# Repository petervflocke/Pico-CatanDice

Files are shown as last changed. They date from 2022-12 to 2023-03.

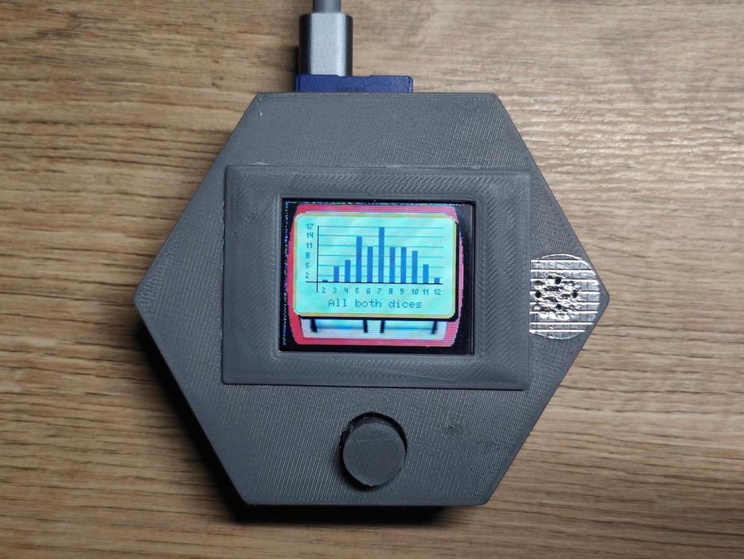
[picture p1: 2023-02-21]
docs/IMG20230221221516.jpg

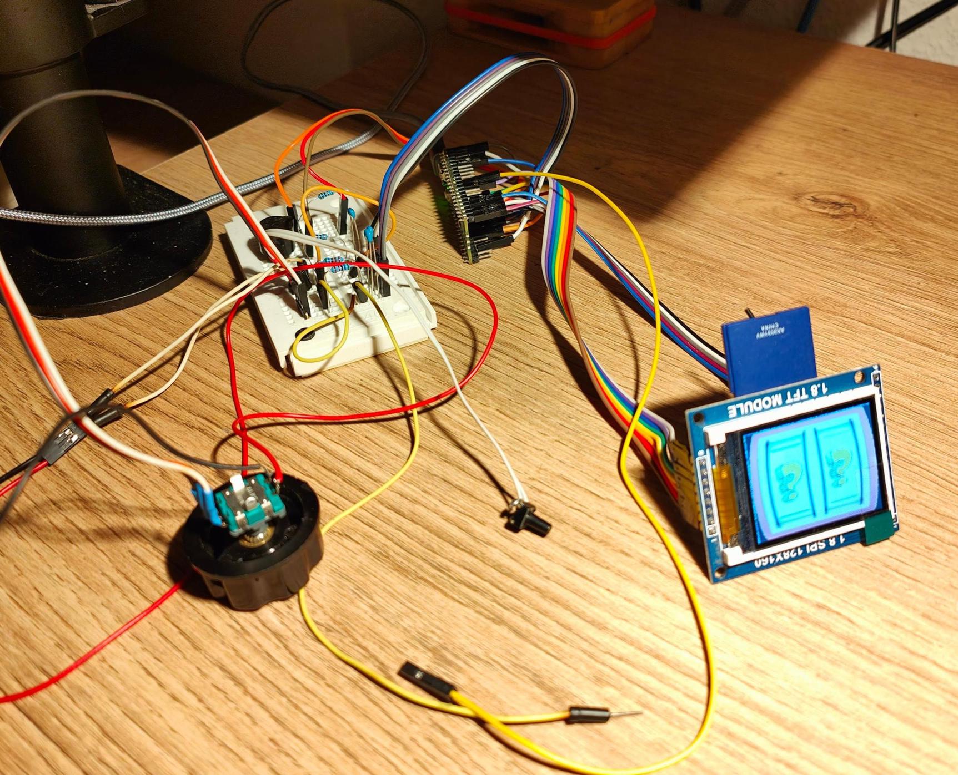
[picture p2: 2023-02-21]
docs/IMG20221118193249.jpg

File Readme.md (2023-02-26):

https://youtube.com/shorts/isAoaTnkfzQ

# An overengineered Catan Dice pretending to be speaking slot machine

Just to learn Raspberry Pi Pico, I've created this random generator I use now to play The Settlers of Catan.

## Main features

- Generating two random numbers from 1 to 6. The randomness is based on some none deterministic factors such as:

    - shifting an internal register
    - random time between button pressed
    - value of a two floating ADC inputs

- Animate generated numbers. Here pico pretends to be a slot machine with some simple sound efects

- Speak out result (showing is boring and pic has a lot of memory for some wav-data).
    - You can use at the same time simple [tone](https://www.arduino.cc/reference/en/language/functions/advanced-io/tone/) function and mix it with wav-data.

    - Wav-data is fully played using DMA, no IRQ no uProcesor cycles, so it does not stop main program. This just a PoC for any other sound efexct in the bacground.

- Show statistics from this game and all prevoius saved on a sd-card, to check if it is really [random](https://dilbert.com/strip/2001-10-25). 

## Miscelenius  

- Check 3D folder for enclousure (you may need a file to let usb and sd card in, in one version)
    - The top of the enclusure was designed for location of my elements, check pictures to copy it, otherwise your component may not match the 3D model.

- Check docs & wiring folder for schematics and some pictures from DIY

- BOM:

    - RPI Pico
    - LCD 1.8" with SD card slot
    - Phone mini loudspeaker 
    - Rotary Encoder
    - few resistors, capcitors

... Some further details in preperation or on a request.

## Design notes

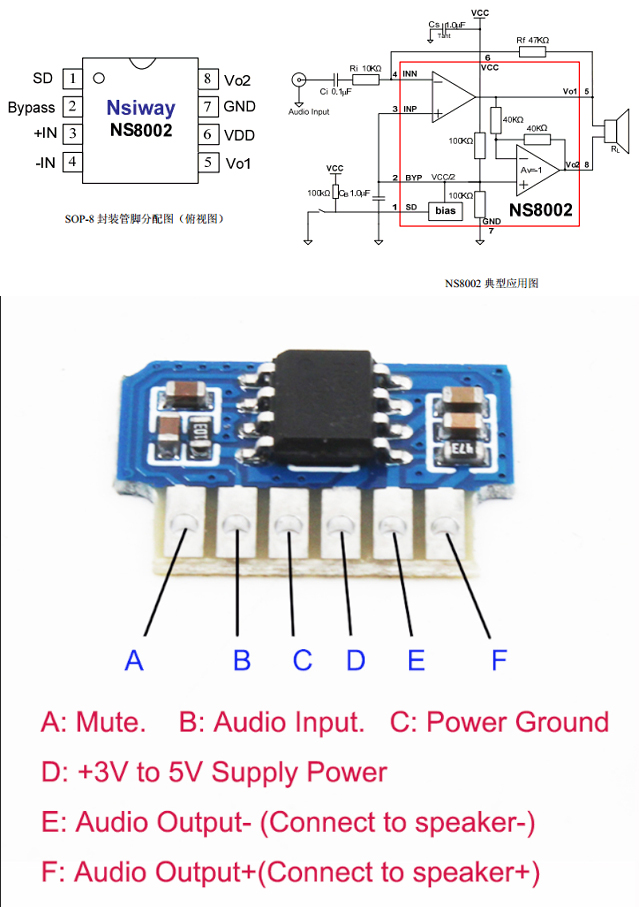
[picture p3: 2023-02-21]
docs/amplifier-NS8002.jpg

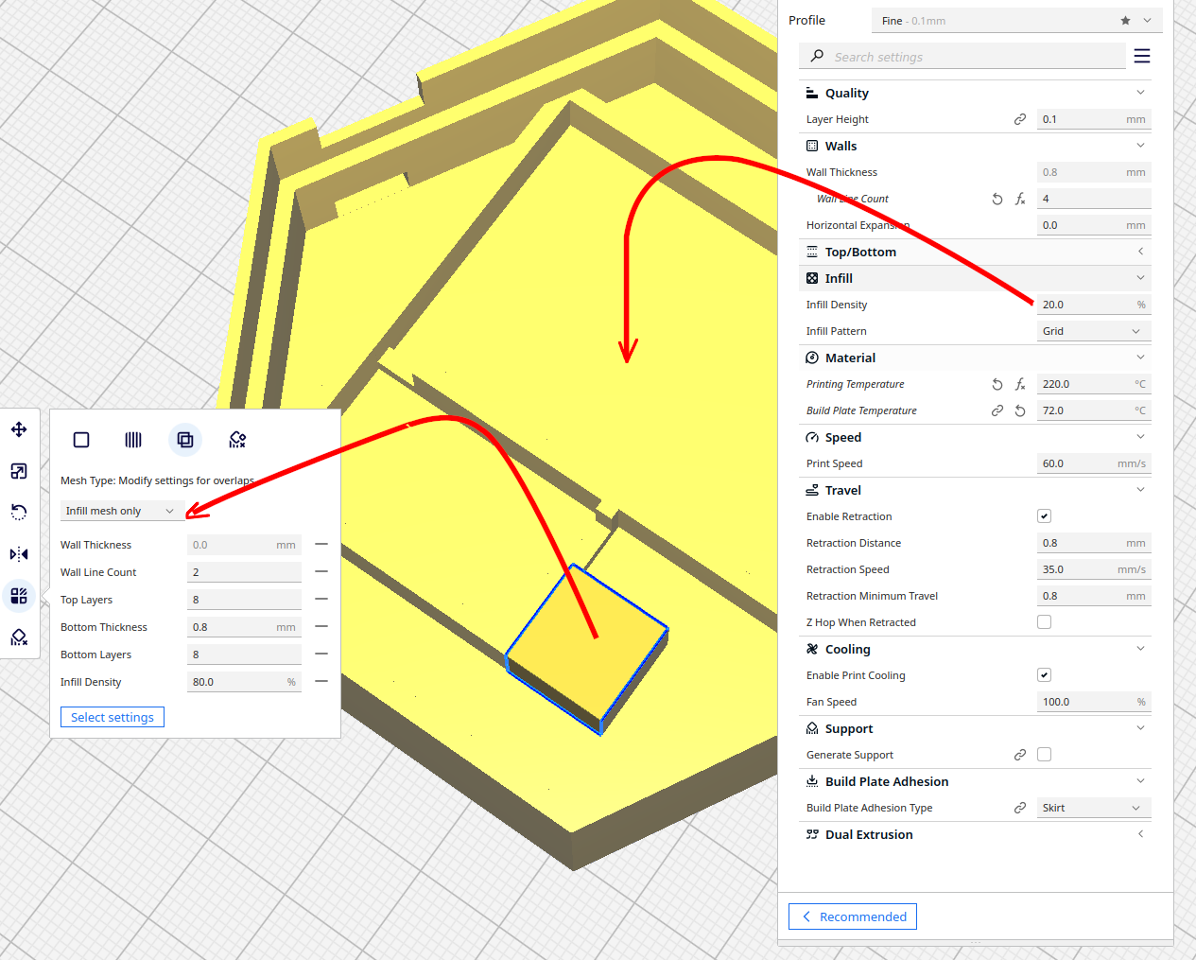
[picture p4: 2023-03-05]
3d/IncreaseDensityFill.png

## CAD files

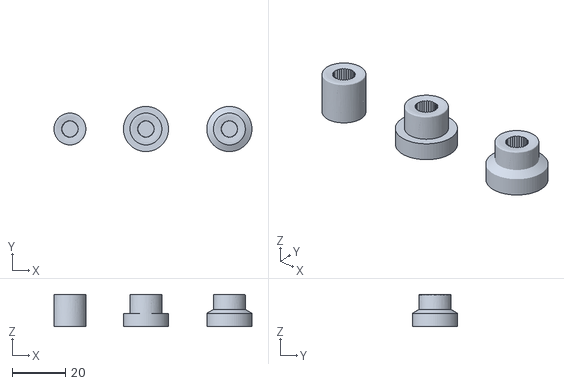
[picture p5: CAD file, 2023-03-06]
3d/Poti-v2.stl
74.5 x 17.0 x 12.1

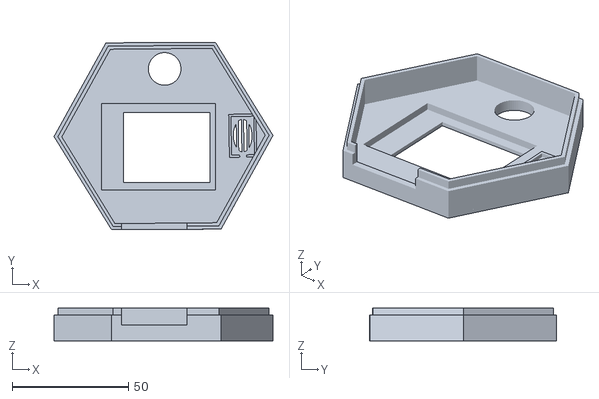
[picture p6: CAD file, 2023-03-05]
3d/CatanDiceBottomTop.stl
94.0 x 80.5 x 14.0

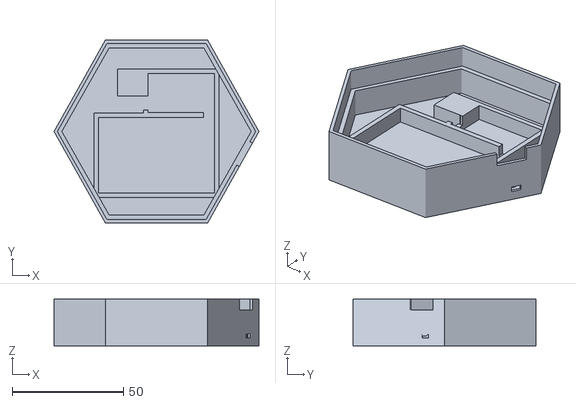
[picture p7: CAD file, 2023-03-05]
3d/CatanDiceBottom.stl
92.0 x 82.0 x 21.0

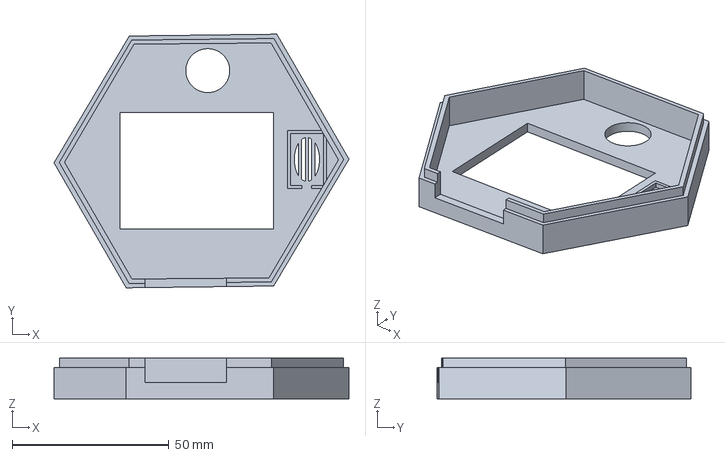
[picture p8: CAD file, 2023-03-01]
3d/CatanDice2.3mf
94.0 x 80.8 x 13.0 mm

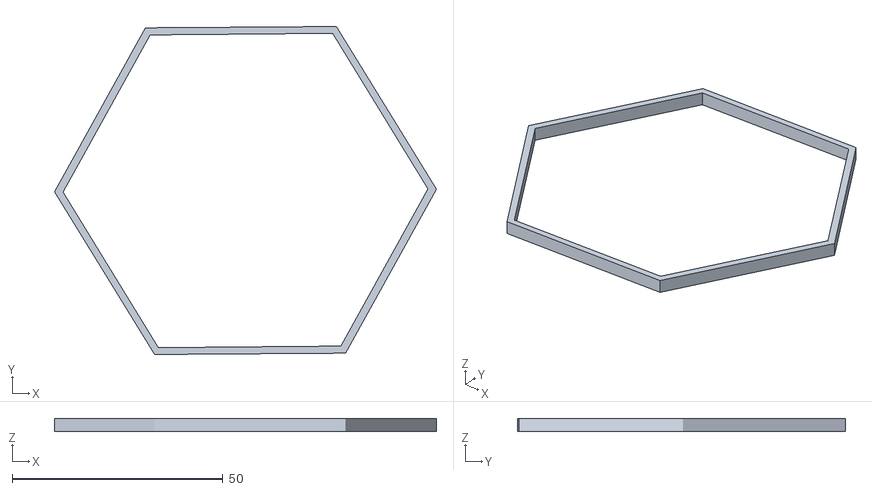
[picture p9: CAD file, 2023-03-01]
3d/CatanDice distance.stl
90.7 x 77.8 x 3.20

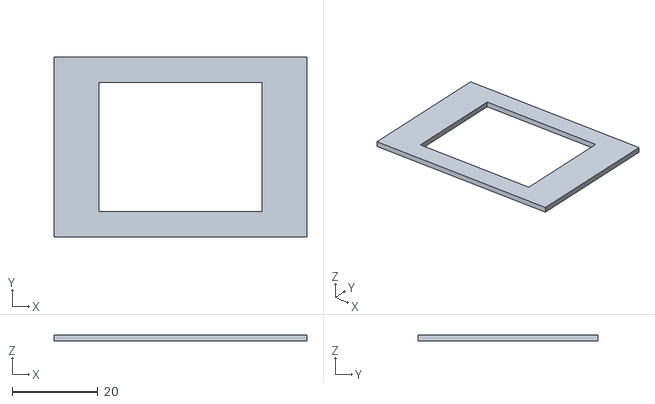
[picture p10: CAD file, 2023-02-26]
3d/CatanDiceBottomTopTop.stl
59.0 x 42.0 x 1.50

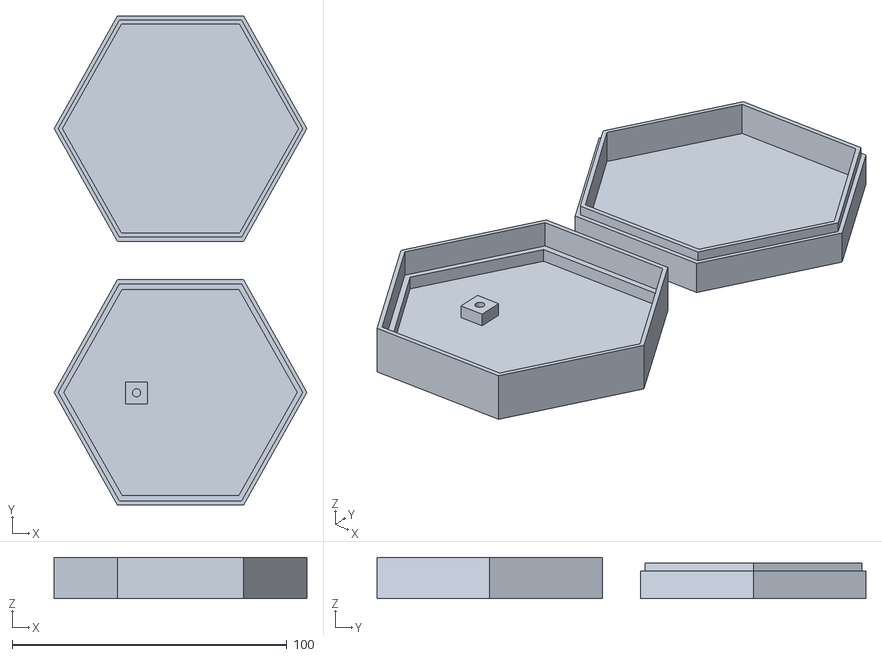
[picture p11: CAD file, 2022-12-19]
3d/CatanDice.stl
92.0 x 178.0 x 15.0

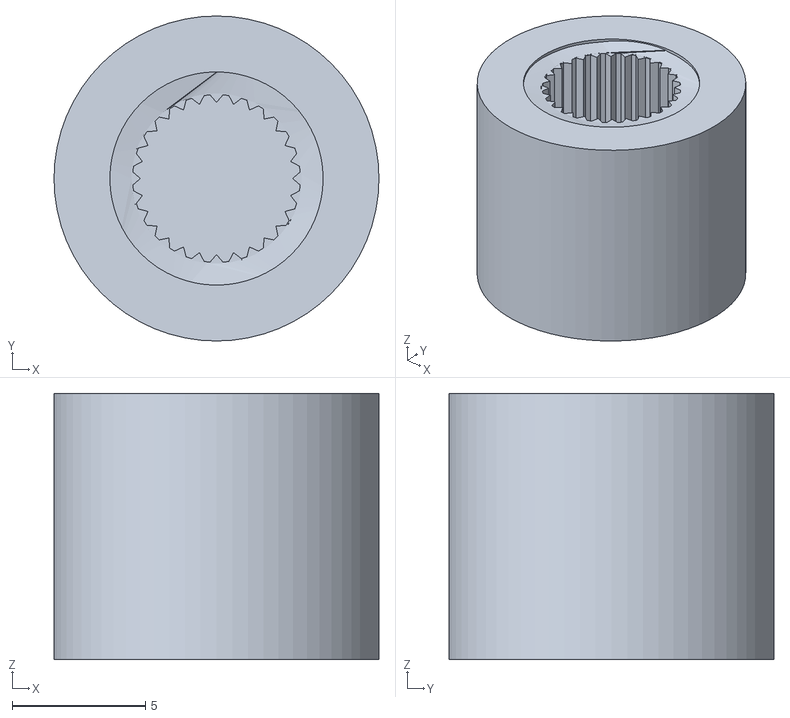
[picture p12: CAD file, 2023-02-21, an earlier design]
3d/Poti.stl
12.2 x 12.2 x 10.0

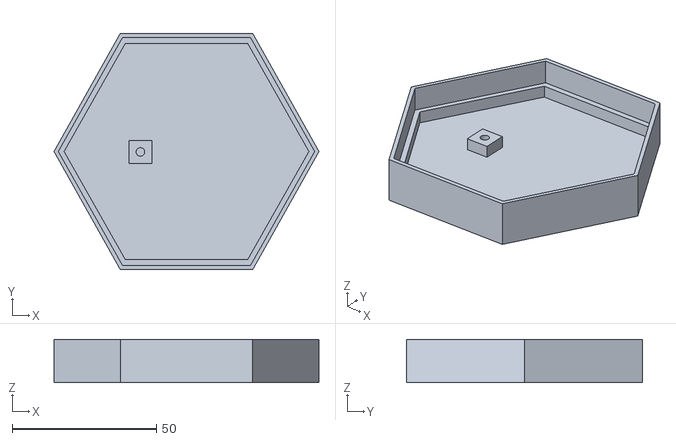
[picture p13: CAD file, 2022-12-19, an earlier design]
3d/CatanDice (1).stl
92.0 x 82.0 x 15.0

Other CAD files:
3d/CatanDice (3).stl
3d/CatanDice (2).stl

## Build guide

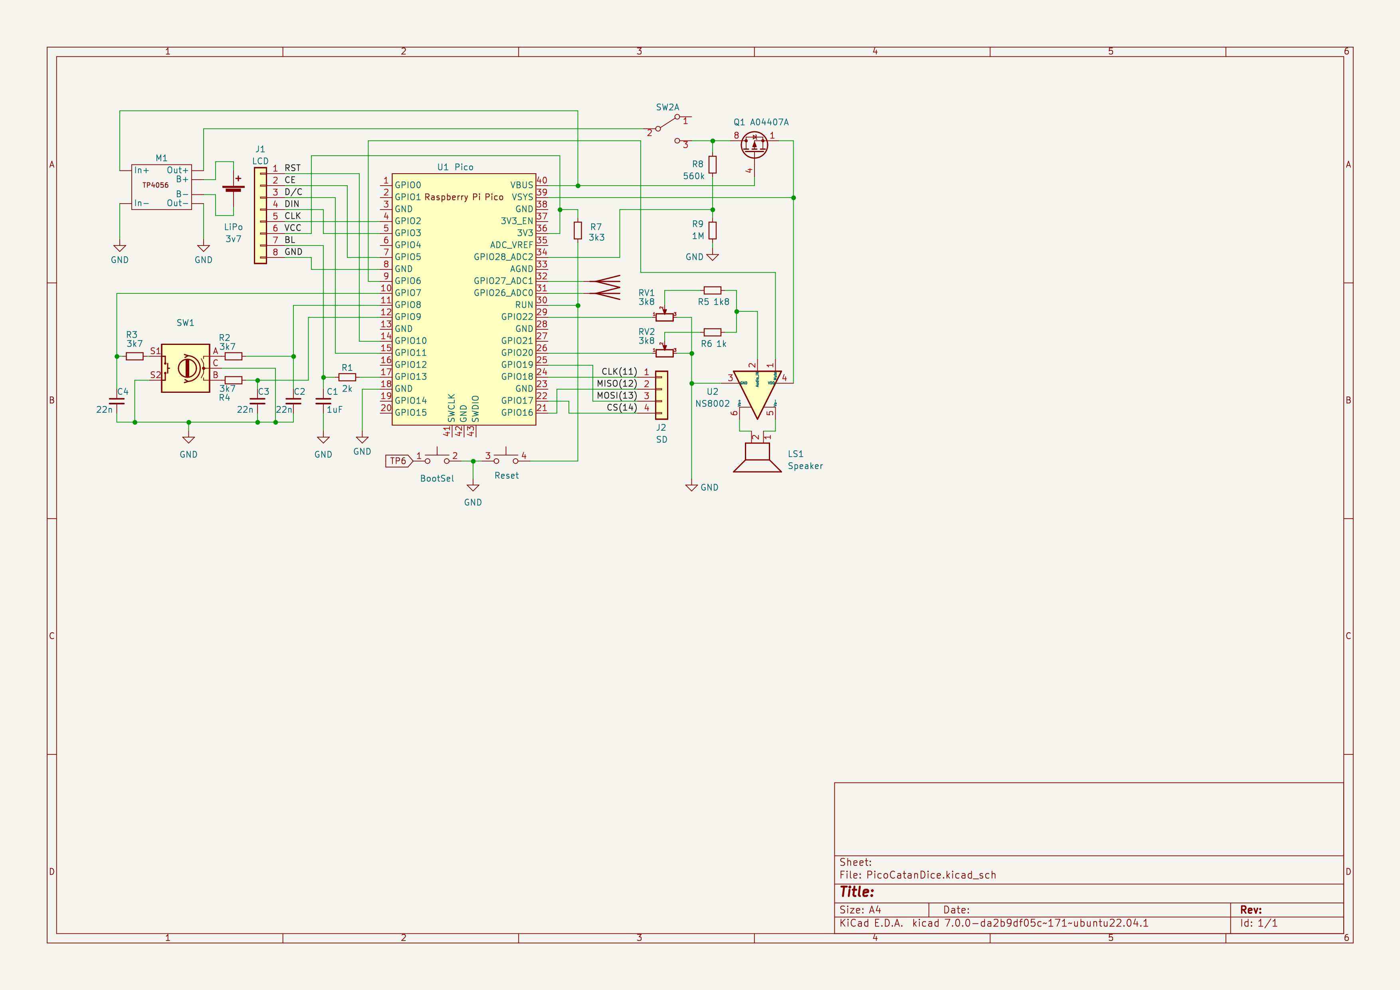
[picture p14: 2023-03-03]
wiring/PicoCatanDice.png

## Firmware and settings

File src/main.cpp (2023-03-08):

/* cSpell:disable */
// #define DEBUG_RANDOM
#ifndef ARDUINO_ARCH_RP2040
  #error works only on earlephilhower core
#endif
#include "Arduino.h"
#include <stdio.h>
#include "hardware/gpio.h"
#include "hardware/regs/rosc.h"
#include "hardware/regs/addressmap.h"
#include <TFT_eSPI.h> 
#include "Free_Fonts.h"
#include <RingBufCPP.h>
#include <ptScheduler.h>
#include "SdFat.h"
#include "settings.h"
#include "songs.h"
#include "logger.h"
#include "graphics.h"
#include "keyhandler.h"
#include "statehandler.h"
#include "randomgenerator.h"
#include "runningaverage.h"

#include "WavPwmAudio.h"
#include "WAVData.h"

 const unsigned short *wavs[]={
  wav2,
  wav3,
  wav4,
  wav5,
  wav6,
  wav7,
  wav8,
  wav9,
  wav10,
  wav11,
  wav12
 };
#define MAX_COUNT 10


TFT_eSPI tft = TFT_eSPI();  
TFT_eSprite scrollText1  = TFT_eSprite(&tft);

ptScheduler  pt_random_waiting_for_press = ptScheduler(PT_TIME_2S);
ptScheduler  pt_random_display = ptScheduler(PT_TIME_20MS);
ptScheduler  pt_random_say = ptScheduler(PT_TIME_4S);
ptScheduler  pt_delay_bird = ptScheduler(ScreenSaverAnimationDelay);
ptScheduler  pt_song = ptScheduler(1);

// volatile long secuenceN = 0;

// ring buffer
RingBufCPP<struct Event, MAX_NUM_ELEMENTS> buf;

SdFat32 sd;

boolean sdCardOK;
int noteIndex;
state_type stateTable[stateNumber][eventNumber];

RunningAverage ra;

void setup()
{
  Serial.begin(115200);
  // while (!Serial) {
  //   yield();
  // }
  
  // Prepare pins and buttons handling
  pinMode(LED_PIN, OUTPUT);
  pinMode(MutePin, OUTPUT);
  pinMode(pinBut, INPUT_PULLUP);
  pinMode(pinA, INPUT_PULLUP);
  pinMode(pinB, INPUT_PULLUP);

  analogReadResolution(12);
  for (int i = 0; i < maxSample; i++) {
    ra.addValue(analogRead(BatPin));
    delay(10);
  }

  WavPwmInit(GPIO_AUDIO_OUT_LEFT);
  digitalWrite(MutePin, 0); // unmute amplifier

  tft.init();   // old tft.begin();
  tft.setRotation(3);  // landscape upside down
  tft.setSwapBytes(true);

  tft.pushImage(0, 0, catanWidth, catanHeight, catan);
  // sdCardOK = SD.begin(PIN_SD_CS, SPI);
  // sdCardOK = sd.cardBegin(SD_CONFIG);
  sdCardOK = sd.begin(SD_CONFIG);
  if (sdCardOK) {
    // delay(1000);
    // Serial.println("Start reading from SD");
    // long lFreeKB = sd.vol()->freeClusterCount();
    // lFreeKB *= sd.vol()->sectorsPerCluster()/2;
    // Serial.println(lFreeKB);
    sdCardOK = myLogger(sd);
  }
  
  myStat.currentDur = millis();
  if (sdCardOK) {
  // Serial.println("Start writing to SD");
    sdCardOK = saveResult(1, 0, 0, 0, 0, 0, 0, myStat.currentDur);
  }

  if (sdCardOK) {
    tft.setTextColor(TFT_WHITE);
    tft.drawString("SD card OK", SDX2e, SDYe, 2);
    delay(2000);
  } else {
    showSDError(tft);
    tft.setTextColor(TFT_RED);
    while (gpio_get(pinBut)) {
      tft.fillRect(SDX1e, SDYe, 45, 16, sdcardback);
      delay(100);
      tft.drawString("ERROR", SDX1e, SDYe, 2);
      delay(100);
    }    
  }
  tft.fillScreen(TFT_BLACK);
  tft.pushImage(0, 0, counterWidth, counterHeight, counter);
  for (unsigned long i=0; i<=(gHeight-1)*gWidth*1; i+=gWidth*4) {
    genTone();
    tft.pushImage(lx, ly, gWidth, gHeight, space+i);
    tft.pushImage(rx, ry, gWidth, gHeight, space+i);
    delay(20);
  }
  // attached pin irq
  gpio_set_irq_enabled_with_callback(pinBut, GPIO_IRQ_EDGE_FALL | GPIO_IRQ_EDGE_RISE , true, &gpio_callback);
  gpio_set_irq_enabled(pinA, GPIO_IRQ_EDGE_FALL | GPIO_IRQ_EDGE_RISE , true);
  gpio_set_irq_enabled(pinB, GPIO_IRQ_EDGE_FALL | GPIO_IRQ_EDGE_RISE , true);

  initState();

  // unsigned long tt = millis();
  if (sdCardOK) {
    // Serial.println("Start reading");
    if (sdCardOK=!readResult()) {
      // Serial.println("Reading ok");  
    };
  } else myStat.inputError = false;


  // uint32_t freeKB = SD.vol()->freeClusterCount();
  // freeKB *= SD.vol()->blocksPerCluster()/2;
  // Serial.print("Free space KB: ");
  // Serial.println(freeKB);


/*   
  Serial.print("Stop reading after: ");
  Serial.println(millis()-tt);
  // delay(1500-tt);


  Serial.print("allDur     : "); Serial.println(myStat.allDur);
  Serial.print("currentDur : "); Serial.println(myStat.currentDur);
  Serial.print("numberGames: "); Serial.println(myStat.numberGames);
  Serial.print("numberDraws: "); Serial.println(myStat.numberDraws);
  Serial.print("inputError : "); Serial.println(myStat.inputError);
  Serial.print("lineNumberError : "); Serial.println(myStat.lineNumberError);

  for (int i=0; i<6; i++) {
    Serial.print(" L "); Serial.print(i+1); Serial.print(" : "); Serial.print(statTabLg[i]); Serial.print(" - "); Serial.println( double(statTabLg[i])/float(myStat.numberDraws)*100.0, 2 );
  }
  for (int i=0; i<6; i++) {
    Serial.print(" R "); Serial.print(i+1); Serial.print(" : "); Serial.print(statTabRg[i]); Serial.print(" - "); Serial.println( double(statTabRg[i])/float(myStat.numberDraws)*100.0, 2 );
  }
  Serial.print("i : "); Serial.println(myStat.numberDraws);
  for (int i=0; i<11; i++) {
    Serial.print(" S "); Serial.print(i+2); Serial.print(" : "); Serial.print(statTabSg[i]); Serial.print(" - "); Serial.println( double(statTabSg[i])/float(myStat.numberDraws)*100.0, 2 );
  }
*/
}


void loop()
{ 
  u_int32_t statCnt=0;

  statTab_t  statTabL = {0, 0, 0, 0, 0, 0};
  statTab_t  statTabR = {0, 0, 0, 0, 0, 0};
  statTabS_t statTabS = {0, 0, 0, 0, 0, 0, 0, 0, 0, 0, 0};

  int scrollDelay;
  int steps;

  int rnd1=0; 
  int rnd2=0;
  uint32_t seedL;
  uint32_t seedR;
  int rndSum;
  int messageGLen;
  int messageIndex;
  unsigned long screenSaver = 0;
  
  unsigned int birdN;
  unsigned int BirdX;
  unsigned int BirdY;

  unsigned long loop_i;
  int loop_j;
  bool loop_z;
  bool loop_w;

  char MessageStr[MessageLen];

  uint16_t resultFrameColor;

  unsigned long duration1;
  unsigned long duration2;

  duration1 = millis();

  state_type current_state = random_waiting_for_press;
  state_type former_state = none;
  bool doBreak;

  #define MAXBACKLIGHT 16
  int backlight = MAXBACKLIGHT;

  while (true) {
    if (!buf.isEmpty())
      {
        // current_state = key_logic(former_state);
        current_state = key_logic(current_state);
      }  
/*     if (current_state != former_state) {
      // Serial.print("Old / New State: "); 
      // Serial.print(former_state);
      // Serial.print("->");
      // Serial.println(current_state);
      former_state = current_state;
    }
*/
    if (current_state != former_state) {
      ra.addValue(analogRead(BatPin));
    }

    if (current_state == screen_saver) {
      if (current_state != former_state) {
        tft.pushImage(0, 0, catanWidth, catanHeight, catan);
        birdN = birdMaxN;
        former_state = current_state;
        BirdX = 15; // initilaized only for first removal, then random
        BirdY =  1;
      }
      if (pt_delay_bird.call()) {
        if (birdN >= birdMaxN) {
          restoreBack(tft, BirdX + tabBirds[birdMaxN-1].bx, BirdY + tabBirds[birdMaxN-1].by, tabBirds[birdMaxN-1].b_width, tabBirds[birdMaxN-1].b_height, catanWidth, catan);          
          birdN = 0;
          BirdX = random(15, 46);
          BirdY = random(1, 16);
        }
        else {
          if (birdN > 0) restoreBack(tft, BirdX + tabBirds[birdN-1].bx, BirdY + tabBirds[birdN-1].by, tabBirds[birdN-1].b_width, tabBirds[birdN-1].b_height, catanWidth, catan);
          tft.pushImage(BirdX + tabBirds[birdN].bx, BirdY + tabBirds[birdN].by, tabBirds[birdN].b_width, tabBirds[birdN].b_height, tabBirds[birdN].bird, TFT_WHITE);
          drawTime(tft, 65, 100, duration1);
          birdN += 1;
        }
      }
    } 
    if ( (current_state == ibacklight) || (current_state == dbacklight) ) {
      if (current_state != former_state) {
        int bl = (current_state == ibacklight)? +1:-1;
        backlight += bl;
        if ( backlight < 1  ) backlight = 1;
        if ( backlight > MAXBACKLIGHT ) backlight = MAXBACKLIGHT;
        Serial.println(map(backlight, 1, MAXBACKLIGHT, 1, 128));
        if (backlight == MAXBACKLIGHT) 
          analogWrite(TFT_BL, 255);
        else
          analogWrite(TFT_BL, map(backlight, 1, MAXBACKLIGHT, 1, 128));
        former_state = current_state;
      }
      key_clean();
      key_none();      
    }    
    if (current_state == random_waiting_for_press) {
      if (current_state != former_state) {
        tft.pushImage(0, 0, counterWidth, counterHeight, counter);
        screenSaver = millis();
        former_state = current_state;
      }
      if (pt_random_waiting_for_press.call()) {
        tone(BuzzerPin,NOTE_G2, 6);
        delay(5);
        tone(BuzzerPin,NOTE_GS2, 5);
        delay(5);
      }

      tft.pushImage(lx, ly, gWidth, gHeight, qq+(random(100)%2?1:-1)*random(4)*gWidth);
      delay(25);
      tft.pushImage(rx, ry, gWidth, gHeight, qq+(random(100)%2?1:-1)*random(4)*gWidth);
      delay(25);

      if (millis() - screenSaver > screenSaverTimeout) {
        // current_state = screen_saver;
        key_clean(); // clean keyboard buffer
        key_none();  // go for none event
      }
    } 
    else if ( (current_state == random_waiting_for_release) ) {
      // if (first_run) {
      if (current_state != former_state) {
        duration1 = millis()-duration1 + analogRead(analog1);
        seedrnd(duration1, seedL);
        rnd1 = random(1, 7);
        
        #ifdef DEBUG_RANDOM
        Serial.print("1. random -> "); Serial.println(rnd1);
        // Serial.print(duration1); Serial.print(" -> ");
        // Serial.println(rnd1);
        #endif

        duration2 = millis();
        steps = slowdown[0][0];
        scrollDelay = slowdown[0][1];
        tft.fillCircle(150-ledSize/2, 0+ledSize/2, ledSize/2, TFT_RED);
        tft.drawCircle(150-ledSize/2, 0+ledSize/2, ledSize/2, TFT_WHITE);
        loop_i = 0;

        for (unsigned long i=0; i<=top_pos; i+=gWidth*steps) {
          genTone();
          tft.pushImage(lx, ly, gWidth, gHeight, ptr_start+i);
          tft.pushImage(rx, ry, gWidth, gHeight, ptr_stop -i);
          delay(scrollDelay);
        }
        // first_run = false;
        former_state = current_state;
      }
      if (loop_i <= top_pos) {
        genTone();
        tft.pushImage(lx, ly, gWidth, gHeight, ptr_start+loop_i);
        tft.pushImage(rx, ry, gWidth, gHeight, ptr_stop -loop_i);
        loop_i+=gWidth*steps;
        delay(scrollDelay);
      } else {
        loop_i = 0;
      }
    }
    else if (current_state == random_slow_down) {
      //tft.pushImage(0, 0, counterWidth, ledSize+1, counter);
      duration2 = millis()-duration2 + analogRead(analog0);
      seedrnd(duration2, seedR);
      rnd2 = random(1, 7);
      #ifdef DEBUG_RANDOM
      Serial.print("2. random -> "); Serial.println(rnd2);
      // Serial.print(duration1); Serial.print(" -> ");  
      // Serial.println(rnd2);
      #endif
      steps = slowdown[0][0];
      scrollDelay = slowdown[0][1];
      tft.fillCircle(150-ledSize/2, 0+ledSize/2, ledSize/2, TFT_GREEN);
      tft.drawCircle(150-ledSize/2, 0+ledSize/2, ledSize/2, TFT_WHITE);
      for (unsigned long i=loop_i; i<=top_pos; i+=gWidth*steps) {
        doBreak = checkBreak();
        if (doBreak) {
          break;
        }        
        genTone();
        tft.pushImage(lx, ly, gWidth, gHeight, ptr_start+i);
        tft.pushImage(rx, ry, gWidth, gHeight, ptr_stop -i);
        delay(scrollDelay);
        int slowdown_index = (i/(gWidth*(gHeight-1)))%SlowDownEl;
        steps = slowdown[slowdown_index][0];
        scrollDelay = slowdown[slowdown_index][1];
      }
      tft.pushImage(0, 0, counterWidth, ledSize+1, counter);
      if (!doBreak) {
        // rnd1 = 6;
        // rnd2 = 6;
        bool run1 = true;
        bool run2 = true;
        steps = slowdown[SlowDownEl-1][0];
        for (unsigned long i=0; i<=top_pos; i+=gWidth*steps) {
          genTone();
          if (run1) {
              tft.pushImage(lx, ly, gWidth, gHeight, ptr_start+i);
              if (ptr_start+i >= digits[rnd1]) {
                tft.pushImage(lx, ly, gWidth, gHeight, digits[rnd1]);
                run1 = false;
              }
          }
          if (run2) {   
              tft.pushImage(rx, ry, gWidth, gHeight, ptr_stop-i);
              if (ptr_stop-i <= digits[rnd2]) {
                tft.pushImage(rx, ry, gWidth, gHeight, digits[rnd2]);  
                run2 = false;
              }
          }
          if (!(run1 or run2)) {
            break;
          }
          else {
            delay(scrollDelay);
            scrollDelay += slowdown[SlowDownEl-1][1];
          }
          doBreak = checkBreak();
          if (doBreak) {
            break;
          }    
        }
      }
      if (doBreak) {
        tft.pushImage(lx, ly, gWidth, gHeight, digits[rnd1]);
        tft.pushImage(rx, ry, gWidth, gHeight, digits[rnd2]); 
        delay(scrollDelay);
      }

      // current_state = random_display;      
      key_clean();
      key_none();
    }
    else if (current_state == random_display) {
      if (current_state != former_state) {

        if (sdCardOK) {
          sdCardOK = saveResult(0, rnd1, rnd2, duration1, duration2, seedL, seedR, millis());
        }

        delay(1000);
        key_clean();        
        tft.pushImage(lx, ly, gWidth, gHeight, space);
        tft.pushImage(rx, ry, gWidth, gHeight, space);
        tft.fillRoundRect(rRX+4, rRY+4, rWi, rHi, 5, TFT_BLACK);
        tft.fillRoundRect(rRX  , rRY  , rWi, rHi, 5, TFT_WHITE);

        rndSum = rnd1+rnd2;
        if (rndSum < 10) {
          tft.pushImage(rRX+rWi/2-gWidth/2, rRY+(rHi)/2-mHi/2, gWidth, mHi, digits[rndSum]   +gWidth*dSt);
        } else {
          tft.pushImage(rRX+4,              rRY+(rHi)/2-mHi/2, gWidth, mHi, digits[rndSum/10]+gWidth*dSt);
          tft.pushImage(rRX+4+42+4,         rRY+(rHi)/2-mHi/2, gWidth, mHi, digits[rndSum%10]+gWidth*dSt);
        }
        resultFrameColor = 0;

        statTabL[rnd1-1] += 1;
        statTabR[rnd2-1] += 1;
        statTabS[rndSum-2] += 1;
        statCnt += 1;

        statTabLg[rnd1-1] += 1;
        statTabRg[rnd2-1] += 1;
        statTabSg[rndSum-2] += 1;
        myStat.numberDraws += 1;        

        //#define DEBUG_RANDOM
        #ifdef DEBUG_RANDOM
        Serial.print("Count : "); Serial.println(statCnt);
        for (int i=0; i<6; i++) {
          Serial.print(" L "); Serial.print(i+1); Serial.print(" : "); Serial.print(statTabL[i]); Serial.print(" - "); Serial.println( double(statTabL[i])/float(statCnt)*100.0, 2 );
        }
        for (int i=0; i<6; i++) {
          Serial.print(" R "); Serial.print(i+1); Serial.print(" : "); Serial.print(statTabR[i]); Serial.print(" - "); Serial.println( double(statTabR[i])/float(statCnt)*100.0, 2 );
        }
        Serial.print("i : "); Serial.println(statCnt);
        for (int i=0; i<11; i++) {
          Serial.print(" S "); Serial.print(i+2); Serial.print(" : "); Serial.print(statTabS[i]); Serial.print(" - "); Serial.println( double(statTabS[i])/float(statCnt)*100.0, 2 );
        }
        #endif

        snprintf_P(MessageStr, sizeof(MessageStr), 
            /* PSTR("Press START to continue. [%d] L:%d %.0f%% | R:%d %.0f%% | S:%d %.0f%%"), */
            MessageText1,
            statCnt,
            rnd1,   float(statTabL[rnd1-1])/statCnt*100.0,
            rnd2,   float(statTabR[rnd2-1])/statCnt*100.0,
            rndSum, float(statTabS[rndSum-2])/statCnt*100.0
        );
        messageGLen = tft.textWidth(MessageStr, 2)+10;
        scrollText1.setColorDepth(8);
        scrollText1.createSprite(rBl+messageGLen, rBh);
        scrollText1.fillSprite(TFT_BLUE);
        scrollText1.setScrollRect(0, 0, rBl+messageGLen, rBh, TFT_BLUE); 
        scrollText1.setTextColor(TFT_WHITE);


        scrollText1.drawString(MessageStr, rBl, 2, 2);
        scrollText1.pushSprite(15, rRY+rHi+9, 0, 0, rBl, rBh);
        messageIndex = messageGLen;

        // Prepare songs
        if ( rndSum != 7) {
          pt_song.setSequenceRepetition(Song2Len * 1); // repeat song 1 time
        } else {
          pt_song.setSequenceRepetition(Song4Len * 2); // repeat song 1 time or 0 for 4ever
        }
        pt_song.reset();
        pt_song.enable();
        noteIndex = 0;

        if (BuzzerPin == GPIO_AUDIO_OUT_LEFT)
          WavPwmInit(GPIO_AUDIO_OUT_LEFT);
        WavPwmPlayAudio(wavs[rndSum-2]);
        pt_random_say.reset();        
        pt_random_say.setSkipSequence(1);
        pt_random_say.setSequenceRepetition(3);
        
        former_state = current_state;

        // if ( 1 < rndSum && rndSum < 13 ) {
        //   WavPwmPlayAudio(wavs[rndSum-2]);
        //   while (WavPwmIsPlaying());    
        // }

      }       
      // display
      // rndSum = 7;
      u_int32_t framecolor;
      if (pt_random_display.call()) {
        if (pt_random_say.call()) {

          if (BuzzerPin == GPIO_AUDIO_OUT_LEFT)
            WavPwmInit(GPIO_AUDIO_OUT_LEFT);
          WavPwmPlayAudio(wavs[rndSum-2]);
        }
        if (rndSum == 7) {
          if (resultFrameColor%2) framecolor=TFT_RED;
          else                    framecolor=TFT_WHITE;
          framecolor = default_4bit_palette[resultFrameColor];
          tft.drawCircle(rRX+rWi/2, rRY+rHi/2, gWidth/2+10, framecolor);
          tft.drawCircle(rRX+rWi/2, rRY+rHi/2, gWidth/2+11, framecolor);
          tft.drawCircle(rRX+rWi/2, rRY+rHi/2, gWidth/2+12, framecolor);
          tft.drawCircle(rRX+rWi/2, rRY+rHi/2, gWidth/2+13, framecolor);
        } else {
          framecolor = TFT_GOLD;
          // genTone();
        }
        tft.drawRoundRect(rRX-1  , rRY-1  , rWi, rHi, 5, framecolor);
        tft.drawRoundRect(rRX    , rRY    , rWi, rHi, 5, framecolor);
        tft.drawRoundRect(rRX+1  , rRY+1  , rWi, rHi, 5, framecolor);
        resultFrameColor = (resultFrameColor + 1) % 15;
        scrollText1.scroll(-1);
        messageIndex -= 1;
        if (messageIndex <=0) {
          messageIndex = messageGLen;
          scrollText1.drawString(MessageStr, rBl, 2, 2);
        }
        scrollText1.pushSprite(15, rRY+rHi+9, 0, 0, rBl, rBh);
      }
      // Play a song
      if (rndSum == 7) {
        genSignal(pt_song, song4, Song4Len, Song4Tempo, noteIndex);
      } else {
        genSignal(pt_song, song2, Song2Len, Song2Tempo, noteIndex);
      }
    }
    else if (current_state == show_statistics) {

      // pt_song.disable();

      #define KEEP_
      #ifndef KEEP_

      // scrollText1.deleteSprite();
      tft.pushImage(0, 0, counterWidth, counterHeight, counter);
      tft.fillRoundRect(sRX+4, sRY+4, sWi, sHi, 5, TFT_BLACK);
      tft.fillRoundRect(sRX  , sRY  , sWi, sHi, 5, TFT_WHITE);
      tft.drawRoundRect(sRX-1, sRY-1, sWi, sHi, 5, TFT_GOLD);
      tft.drawRoundRect(sRX  , sRY  , sWi, sHi, 5, TFT_GOLD);
      tft.drawRoundRect(sRX+1, sRY+1, sWi, sHi, 5, TFT_GOLD);
      tft.drawFastVLine(sRX+2*sXY, sRY+sXY, sHi-2*sXY, TFT_BLACK);
    
      tft.setFreeFont(TT1);
      tft.setTextColor(TFT_BLUE,TFT_WHITE);  tft.setTextSize(1);
      
      u_int32_t maxProb = 0;
      for (int i=0; i<11; i++) {
        maxProb = (maxProb < statTabS[i]? statTabS[i] : maxProb);
      }
      maxProb = 100*maxProb/statCnt;
      // Serial.print("maxProb :"); Serial.println(maxProb);
      for (int i=maxProb; i > 0; i-=maxProb/5) {
        tft.drawNumber(i, sRX+sXY-(i==100?2:0), sRY+sXY+(((maxProb-i)*(sHi-3*sXY)/maxProb))-2);
        tft.drawFastHLine(sRX+2*sXY+1, sRY+sXY+((maxProb-i)*(sHi-3*sXY)/maxProb), sWi-3*sXY-1, TFT_LIGHTGREY);
      }
      tft.drawFastHLine(sRX+sXY, sRY+sHi-2*sXY, sWi-2*sXY, TFT_BLACK);
      for (int i=0; i<11; i++) {
        int barHight=100*statTabS[i]/statCnt;
        // Serial.print(i+2); Serial.print(" : "); Serial.print(barHight);
        barHight = map(barHight, 0, maxProb, 0, sHi-3*sXY);
        // Serial.print(" : "); Serial.println(barHight);
        tft.fillRect (sRX+2*sXY+sBw+i*(sBw+sBm), sRY+sHi-2*sXY-barHight, sBw, barHight, TFT_BLUE);
        tft.drawNumber(i+2, sRX+2*sXY+sBw+i*(sBw+sBm), sRY+sHi-2*sXY+sBm);
      }
      #endif
      //drawChart(statTabS, 11, 2);
      // drawChart(statTabL, 6, 1);
      // drawChart(statTabR, 6, 1);
      // drawBarChart(sum_of_both);
      // drawBarChart(left_and_Right);

      drawBarChart(tft, statTabL, statTabR, statTabS, statCnt, left_and_Right, "old");
      // drawBarChart(tft, statTabL, statTabR, statTabS, statCnt, sum_of_both);
      delay(200);
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

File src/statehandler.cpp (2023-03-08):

/* cSpell:disable */
#include "Arduino.h"
#include "statehandler.h"
#include "keyhandler.h"


inline state_type& operator++(state_type& state, int) {
    const int st_ = static_cast<int>(state)+1;
    state = static_cast<state_type>((st_) % stateNumber);
    return state;
}

void initState () {
  for (state_type i=none; i<thened; i++) {
    // zero => none the complete mapping state table none => keep old state
    stateTable[i][e_none]=none;
    stateTable[i][e_right]=none;
    stateTable[i][e_left]=none;
    stateTable[i][e_down]=none;
    stateTable[i][e_up]=none;
  }
  // initiate button and none-button actions for existing machine states
  // current state + button direction => new state
  stateTable[random_waiting_for_press]  [e_down]  =  random_waiting_for_release;
  stateTable[random_waiting_for_press]  [none]    =  screen_saver;

  stateTable[random_waiting_for_press]  [e_right] =  sbacklight;
  stateTable[random_waiting_for_press]  [e_left]  =  show_summary;

  stateTable[sbacklight]                [e_up]    =  ebacklight;
  stateTable[sbacklight]                [e_right] =  show_statistics_Single;
  stateTable[sbacklight]                [e_left]  =  random_waiting_for_press;

  stateTable[ebacklight]                [e_up]    =  sbacklight;
  stateTable[ebacklight]                [e_right] =  ibacklight;
  stateTable[ebacklight]                [e_left]  =  dbacklight;
  stateTable[ibacklight]                [none]    =  ebacklight;
  stateTable[dbacklight]                [none]    =  ebacklight;
  
  stateTable[show_statistics_Single]    [e_up]    =  random_waiting_for_press;
  stateTable[show_statistics_Single]    [e_right] =  show_statistics_Sum;
  stateTable[show_statistics_Single]    [e_left]  =  sbacklight;
  
  stateTable[show_statistics_Sum]       [e_up]    =  random_waiting_for_press;
  stateTable[show_statistics_Sum]       [e_right] =  show_statistics_SingleAll;
  stateTable[show_statistics_Sum]       [e_left]  =  show_statistics_Single;

  stateTable[show_statistics_SingleAll] [e_up]    =  random_waiting_for_press;
  stateTable[show_statistics_SingleAll] [e_right] =  show_statistics_SumAll;
  stateTable[show_statistics_SingleAll] [e_left]  =  show_statistics_Sum;

  stateTable[show_statistics_SumAll]    [e_up]    =  random_waiting_for_press;
  stateTable[show_statistics_SumAll]    [e_right] =  show_summary;
  stateTable[show_statistics_SumAll]    [e_left]  =  show_statistics_SingleAll;

  stateTable[show_summary]              [e_up]    =  random_waiting_for_press;
  stateTable[show_summary]              [e_right] =  random_waiting_for_press;
  stateTable[show_summary]              [e_left]  =  show_statistics_SumAll;

  // stateTable[show_statistics]           [none]    =  wait_in_statistics;

  stateTable[random_waiting_for_release][e_up]    =  random_slow_down;
  stateTable[random_slow_down]          [none]    =  random_display;

  stateTable[random_display]            [e_up]    =  before_waiting_for_press;
  // stateTable[random_display]            [e_right] =  show_statistics_Single; 
  // stateTable[random_display]            [e_left]  =  show_summary;

  // stateTable[random_display]            [e_right] =  ibacklight;
  // stateTable[random_display]            [e_left]  =  dbacklight;
  // stateTable[ibacklight]                [none]    =  random_display;
  // stateTable[dbacklight]                [none]    =  random_display;


/*
  stateTable[wait_in_statistics]        [e_up]    =  before_waiting_for_press;
  stateTable[wait_in_statistics]        [e_right] =  show_statistics_Single;
  stateTable[wait_in_statistics]        [e_left]  =  show_statistics_Sum;
*/

  stateTable[before_waiting_for_press]  [none]    =  random_waiting_for_press;

  stateTable[screen_saver]              [e_up]    =  random_waiting_for_press;
  stateTable[screen_saver]              [e_right] =  random_waiting_for_press;
  stateTable[screen_saver]              [e_left]  =  random_waiting_for_press;

}
  

state_type key_logic(state_type old_state) {
  struct Event e;
  state_type new_state=none;
  
  noInterrupts();
  bool data=buf.pull(&e);
  interrupts();
  
  if (data) { 

    // Serial.print("Pin state     : "); Serial.println(e.pinState, BIN);
    // Serial.print("Pin number    : "); Serial.println(e.pinNum);
    // Serial.print("Direction    : "); Serial.println(e.direction);
    // Serial.print("Timestamp (ms): "); Serial.println(e.timestamp);

    new_state = stateTable[old_state][e.direction];
    // if (new_state == none) new_state = old_state; // none => no action defined, keep state

  }
  return (new_state == none)? old_state:new_state;
}

/* // not more maintained hardcoded state logic / instead of data based logic 
state_type key_logic(state_type old_state) {
  struct Event e;
  state_type new_state=none;
  
  noInterrupts();
  bool data=buf.pull(&e);
  interrupts();
  
  if (data) { 

    // Serial.print("Pin state     : "); Serial.println(e.pinState, BIN);
    // Serial.print("Pin number    : "); Serial.println(e.pinNum);
    // Serial.print("Direction    : "); Serial.println(e.direction);
    // Serial.print("Timestamp (ms): "); Serial.println(e.timestamp);


    if (old_state == random_waiting_for_press and e.direction == e_down)
      {
        new_state = random_waiting_for_release;
      } 
    else if (old_state == random_waiting_for_release and e.direction == e_up)
      {
        new_state = random_slow_down;
      } 
    else if (old_state == random_display and e.direction == e_up)
      {
        new_state = before_waiting_for_press;
      }
    else if (old_state == random_display and e.direction == e_right)
      {
        new_state = show_statistics_Single;
      }
    else if (old_state == random_display and e.direction == e_left)
      {
        new_state = show_statistics_Sum;
      }
    else if (old_state == wait_in_statistics and e.direction == e_up)
      {
        new_state = before_waiting_for_press;
      }
    else if (old_state == wait_in_statistics and e.direction == e_right)
      {
        new_state = show_statistics_Single;
      }
    else if (old_state == wait_in_statistics and e.direction == e_left)
      {
        new_state = show_statistics_Sum;
      }
    else new_state = old_state;
  }
  return new_state;
}
 */ 

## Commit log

2022-11-20 global statistics
    [dice.csv]
2022-11-20 corrected pt_song / reste
    [main.cpp]
2022-11-22 sdcard show error (testing)
    [main.cpp]
2022-11-27 new SD card handler
    [dice.csv, dice1.csv]
2022-11-28 new encoder rutine and circuit drawing
    [CatanDice.fzz]
2022-12-06 minor changes
    [CatanDice.fzz]
2022-12-06 screensaver rework, reduce tft SPI to 3MHz to eliminate artefacts
    [graphics.cpp, graphics.h, main.cpp]
2022-12-19 Some updates, not relevant to comment :)
    [CatanDice (1).stl, CatanDice (2).stl, CatanDice (3).stl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]
2023-02-19 Added voice over of result
    [dice.csv, dice1.csv]
2023-02-19 start wiring
2023-02-19 Schematic init
    [PicoCatanDice.kicad_pcb, PicoCatanDice.kicad_sch]
2023-02-21 Readme and pics
    [Poti.stl]
2023-02-22 Backlight PWM channel change
2023-02-23 fix bakclight humming, needed hardware low pass filter
    [CatanDice.fzz]
2023-02-26 3D models
    [CatanDiceBottom.stl, CatanDiceBottomTop.stl, CatanDiceBottomTopTop.stl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]
2023-03-01 3D enclusure updates
    [CatanDice distance.stl, CatanDice.fzz, CatanDice2.3mf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]
2023-03-03 Added battery check
    [PicoCatanDice.kicad_sch]
2023-03-05 Battery voltage measurement
    [CatanDiceBottom.stl, CatanDiceBottomTop.stl]
2023-03-05 Update 3D models
    [CatanDiceBottomTop-v2.stl, CatanDiceBottomTop.stl]
2023-03-08 Battery and backlight
2023-03-08 finished battery display
